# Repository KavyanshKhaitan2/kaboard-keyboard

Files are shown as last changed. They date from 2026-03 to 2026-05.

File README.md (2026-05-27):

# Kaboard!
[[ Showcase video ]](https://youtu.be/ID2R_xTHKyI)

_Yet another mechanical keyboard_

This is the first full-size keyboard I built!

It is a full-size mechanical keyboard with LEDs under each key. The firmware is very customisable, you can customise everything using usevia.app.

## Contents
Quickly jump to different sections of this README.
1. [Why?](#why)
1. [Fallout Zine Page](#zine)
1. [PCB](#pcb)
2. [Schematics](#schematics)
3. [Case](#case)
4. [BOM](#bom)
5. [How do I build it?](#how-do-i-build-it)
## Why?
I wanted to learn how to build a keyboard, so this is how I decided to do that!

## Zine
Kaboard! Zine (1)

## PCB


[ [View in KiCanvas](https://kicanvas.org/?repo=https://github.com/KavyanshKhaitan2/kaboard-keyboard/tree/main/pcb) ]

## Schematics



## Case
[ [View in Onshape](https://cad.onshape.com/documents/8ed13534193dd50e2cf177a7/w/262d5483b57866700addb319/e/d3e08e0b5eff8c35a30b137c) ] 
### Top
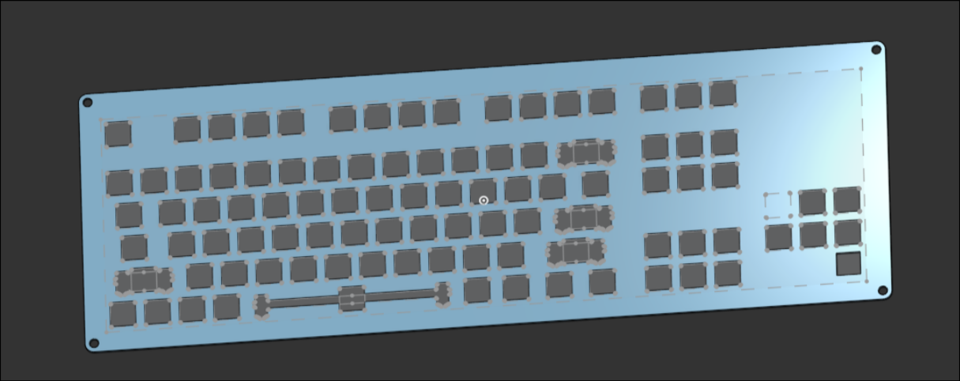
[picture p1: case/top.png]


[ [Download STEP file](https://github.com/KavyanshKhaitan2/kaboard-keyboard/raw/refs/heads/main/case/bottom.step) ]
### Bottom
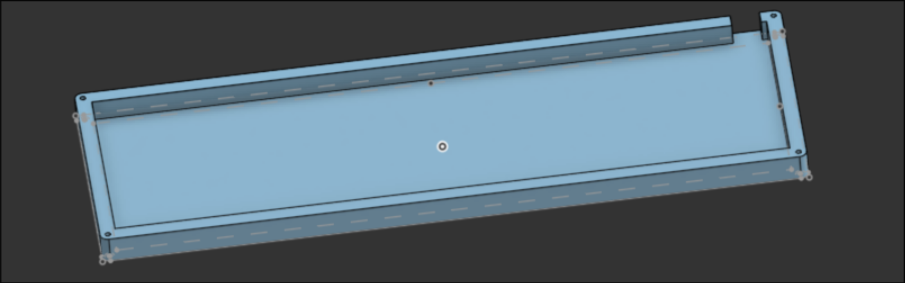
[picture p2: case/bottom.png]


[ [Download STEP file](https://github.com/KavyanshKhaitan2/kaboard-keyboard/raw/refs/heads/main/case/top.step) ]

## BOM
| Item | Qty | Link | Price | Running total |
|---|-----|---|---|---:|
| Keycaps | 1 set |  [StacksKB](https://stackskb.com/store/veekos-gradient-keycaps-cherry-profile-135-keys/) | Rs. 1300 (~ $15) | Rs. 1300 ($15) |
| Switches | 100pc | [CosmicByte](https://www.thecosmicbyte.com/product/gateron-mechanical-switches-compatible-with-cosmic-byte-hot-swappable-keyboards-qty-1pc/) | Rs. 2000 (~ $25) | Rs. 3300 ($40) |
| Resettable Fuse | 1 | [LCSC](https://www.lcsc.com/product-detail/C2153776.html) | $2 (~ Rs. 200) | Rs. 3500 ($42) |
| Raspberry Pi Pico | 1 | [Robu](https://robu.in/product/raspberry-pi-pico/) | Rs. 400 (~ $5) | Rs. 3900 ($47) |
| 1k resistor | 2 | [LCSC](https://www.lcsc.com/product-detail/C119870.html) | $0.60 (~ Rs. 60) | Rs. 3960 ($47.6) |
| 1N4148 diodes | 96 | [LCSC](https://www.lcsc.com/product-detail/C84410.html) | $1.6 (~ Rs. 160) | Rs. 4120 ($49.2) |
| EC11 rotary encoder | 1 | - | 0 | Rs. 4120 ($49.2) |
| SK6812MINI-E | 120 | [LCSC](https://www.lcsc.com/product-detail/C5149201.html?s_z=n_SK6812MINI-E) | $9 (~ Rs. 900) | Rs. 5020 ($58.2) |
| PCB | 1 | AIVON | $25.3 (~Rs. 2300) | Rs. 7320 ($83.5) |
| Keycap Stabilizers | 8 | [StacksKB](https://stackskb.com/store/genuine-cherry-mx-plate-mount-stabilizers-2u/) | Rs. 400 (~$4) | Rs. 7720 ($87.5) |
| Spacebar Stabilizer Wire | 1 | Self fulfilled | Rs. 0 | Rs. 7720 ($87.5) |
| Shipping (Guesstimate) | - | - | $25 (~Rs. 2500) | Rs. 10220 ($112.5) |

## How do I build it?
1. Obtain all of the BoM.
2. Print the 3d case
3. Start soldering the SK6812MINI-Es
4. Solder all the diodes
5. Solder the pi pico from the back
6. Solder the rotary encoder
7. Add the stabilizers to the top part of the case
8. Get the top part of the case and place it over the pcb
9. Get all the switches and place it through the case
10. Solder all the switches that you just placed
11. Plug it in to your computer in BOOTSEL mode
12. Upload the .uf2 firmware file over to the drive that just got mounted
13. Voilla! You are now done!

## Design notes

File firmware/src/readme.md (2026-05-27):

# kaboard

kaboard

*A short description of the keyboard/project*

* Keyboard Maintainer: [Kavyansh Khaitan](https://github.com/KavyanshKhaitan2)
* Hardware Supported: *The PCBs, controllers supported*
* Hardware Availability: *Links to where you can find this hardware*

Make example for this keyboard (after setting up your build environment):

    make kaboard:default

Flashing example for this keyboard:

    make kaboard:default:flash

See the [build environment setup](https://docs.qmk.fm/#/getting_started_build_tools) and the [make instructions](https://docs.qmk.fm/#/getting_started_make_guide) for more information. Brand new to QMK? Start with our [Complete Newbs Guide](https://docs.qmk.fm/#/newbs).

## Bootloader

Enter the bootloader in 3 ways:

* **Bootmagic reset**: Hold down the key at (0,0) in the matrix (usually the top left key or Escape) and plug in the keyboard
* **Physical reset button**: Briefly press the button on the back of the PCB - some may have pads you must short instead
* **Keycode in layout**: Press the key mapped to `QK_BOOT` if it is available

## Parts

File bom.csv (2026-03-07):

Item | Qty | Link | Price | Running total
Keycaps | 1 set | https://stackskb.com/store/veekos-gradient-keycaps-cherry-profile-135-keys/ | Rs. 1300 (~ $15) | Rs. 1300 ($15)
Switches | 100pc | https://www.thecosmicbyte.com/product/gateron-mechanical-switches-compatible-with-cosmic-byte-hot-swappable-keyboards-qty-1pc/ | Rs. 2000 (~ $25) | Rs. 3300 ($40)
Resettable Fuse | 1 | https://www.lcsc.com/product-detail/C2153776.html | $2 (~ Rs. 200) | Rs. 3500 ($42)
Raspberry Pi Pico | 1 | https://robu.in/product/raspberry-pi-pico/ | Rs. 400 (~ $5) | Rs. 3900 ($47)
1k resistor | 2 | https://www.lcsc.com/product-detail/C119870.html | $0.60 (~ Rs. 60) | Rs. 3960 ($47.6)
1N4148 diodes | 96 | https://www.lcsc.com/product-detail/C84410.html | $1.6 (~ Rs. 160) | Rs. 4120 ($49.2)
EC11 rotary encoder | 1 | - | 0 | Rs. 4120 ($49.2)
SK6812MINI-E | 120 | https://www.lcsc.com/product-detail/C5149201.html?s_z=n_SK6812MINI-E | $9 (~ Rs. 900) | Rs. 5020 ($58.2)
PCB | 1 | JLCPCB | $25.3 (~Rs. 2300) | Rs. 7320 ($83.5)
Keycap Stabilizers | 8 | https://stackskb.com/store/genuine-cherry-mx-plate-mount-stabilizers-2u/ | Rs. 400 (~$4) | Rs. 7720 ($87.5)
Keycap Stabilizers | 1 set | https://www.amazon.in/Merishopp-Stabilizers-Precision-Mechanical-Networking/dp/B0FF4F3RZY | Rs. 870 (~$8) | Rs. 8590 ($95.5)
Shipping (Guesstimate) | - | - | $25 (~Rs. 2500) | Rs. 11090 ($120.5)

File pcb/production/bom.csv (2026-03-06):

Designator | Footprint | Quantity | Value | LCSC Part #
A1 | RaspberryPi_Pico_Common_THT | 1 | RaspberryPi_Pico
D1, D10, D11, D12, D13, D14, D15, D16, D17, D18, D19, D192, D2, D20, D21, D22, D23, D24, D25, D26, D27, D28, D29, D3, D30, D32, D33, D34, D35, D36, D37, D38, D39, D4, D40, D41, D42, D43, D44, D45, D46, D47, D48, D49, D5, D50, D51, D52, D53, D54, D55, D56, D57, D58, D59, D6, D60, D61, D62, D63, D64, D65, D66, D67, D68, D69, D7, D70, D71, D72, D73, D74, D75, D76, D77, D78, D79, D8, D80, D81, D82, D83, D84, D85, D86, D87, D88, D89, D9, D90, D91, D92, D93, D94, D95, D96 | D_DO-41_SOD81_P7.62mm_Horizontal | 96 | D
F1 | Fuse_Littelfuse_372_D8.50mm | 1 | 1.6A
LED1, LED10, LED100, LED101, LED102, LED11, LED12, LED13, LED14, LED15, LED16, LED17, LED18, LED19, LED2, LED20, LED201, LED21, LED22, LED23, LED24, LED25, LED26, LED27, LED28, LED29, LED3, LED30, LED31, LED32, LED33, LED34, LED35, LED36, LED37, LED38, LED39, LED4, LED40, LED41, LED42, LED43, LED44, LED45, LED46, LED47, LED48, LED49, LED5, LED50, LED51, LED52, LED53, LED54, LED55, LED56, LED57, LED58, LED59, LED6, LED60, LED61, LED62, LED63, LED64, LED65, LED66, LED67, LED68, LED69, LED7, LED70, LED71, LED72, LED73, LED74, LED75, LED76, LED77, LED78, LED79, LED8, LED80, LED81, LED82, LED83, LED84, LED85, LED86, LED87, LED88, LED89, LED9, LED90, LED91, LED92, LED93, LED94, LED95, LED96, LED97, LED98, LED99 | MX_SK6812MINI-E_REV | 103 | SK6812MINI-E
MX1, MX10, MX11, MX12, MX13, MX14, MX15, MX16, MX17, MX18, MX19, MX2, MX20, MX21, MX22, MX23, MX24, MX25, MX26, MX27, MX28, MX29, MX3, MX30, MX32, MX33, MX34, MX35, MX36, MX37, MX38, MX39, MX4, MX40, MX41, MX42, MX43, MX44, MX45, MX46, MX47, MX48, MX49, MX5, MX50, MX51, MX52, MX53, MX54, MX55, MX56, MX57, MX58, MX59, MX6, MX60, MX61, MX62, MX63, MX64, MX65, MX66, MX67, MX68, MX69, MX7, MX70, MX71, MX72, MX73, MX74, MX75, MX76, MX77, MX78, MX79, MX8, MX80, MX81, MX82, MX83, MX84, MX85, MX86, MX87, MX88, MX89, MX9, MX90, MX91, MX92, MX93, MX94, MX95, MX96 | SW_Cherry_MX_1.00u_PCB_withSwitch | 95 | MX_SW_HS
R1, R2 | R_Axial_DIN0204_L3.6mm_D1.6mm_P5.08mm_Horizontal | 2 | 1K
SW1 | RotaryEncoder_Alps_EC11E-Switch_Vertical_H20mm | 1 | RotaryEncoder_Switch

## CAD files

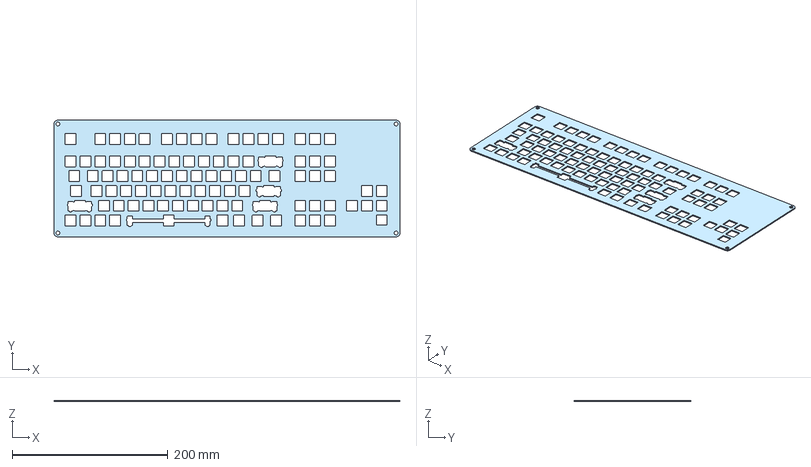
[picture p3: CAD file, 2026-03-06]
case/top.step
444.8 x 150.1 x 1.50 mm

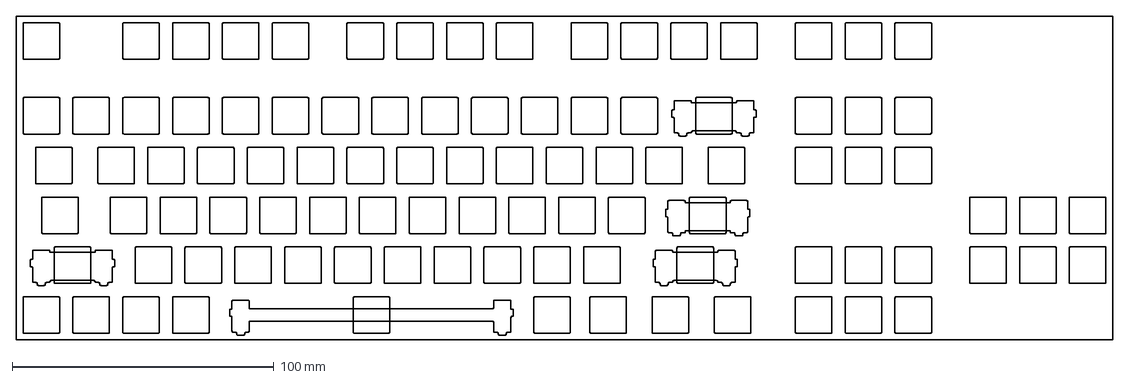
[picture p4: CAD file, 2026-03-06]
plate-2026-03-01T12_22_32.903Z.dxf
419.1 x 123.8 mm

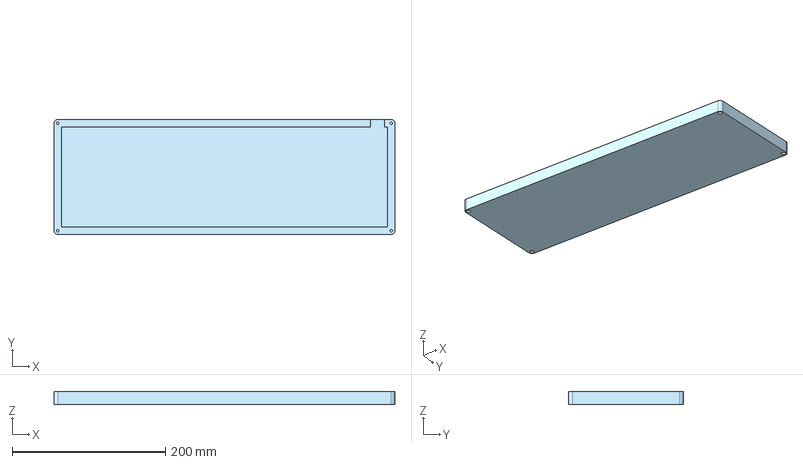
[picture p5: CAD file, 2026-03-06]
case/bottom.step
444.8 x 150.1 x 17.1 mm

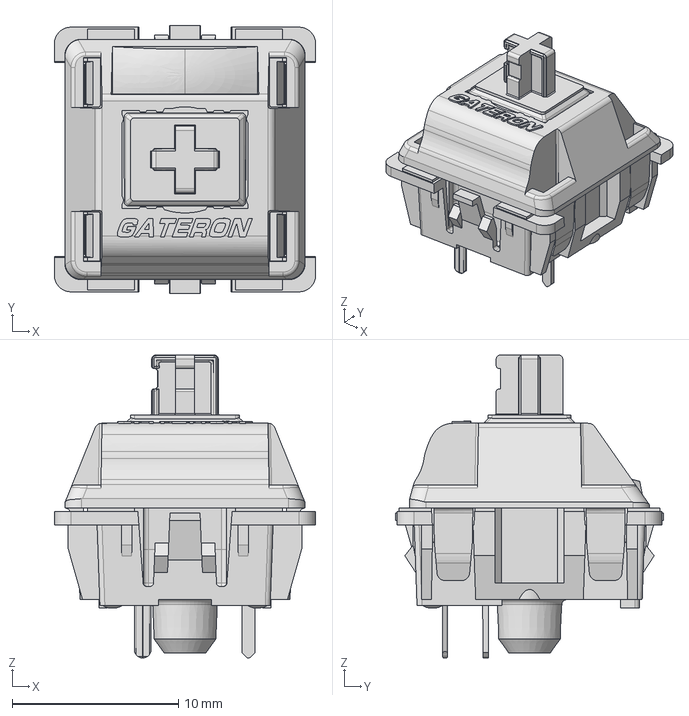
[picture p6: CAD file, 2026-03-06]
G PRO 3.0 Switch KS-9E10B055NN-Y51.stp
15.7 x 16.1 x 18.2 mm

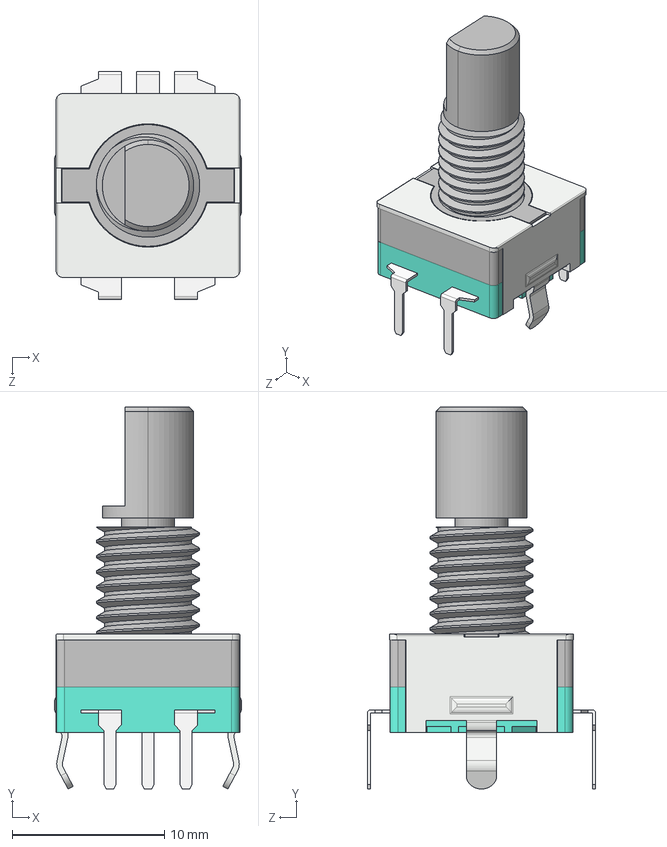
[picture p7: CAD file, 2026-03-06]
EC11 3d model.step
12.3 x 25.1 x 15.0 mm

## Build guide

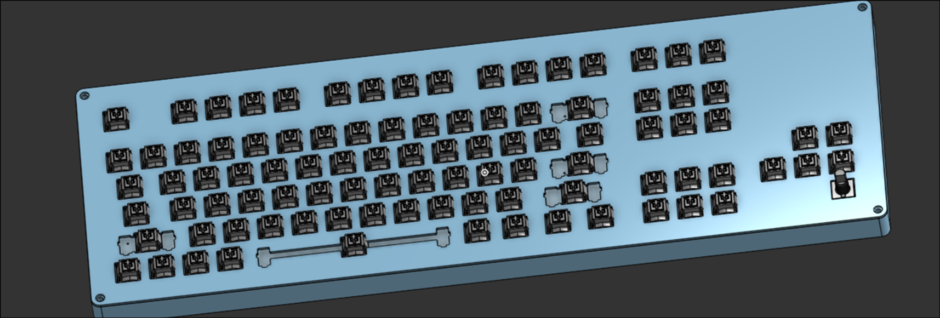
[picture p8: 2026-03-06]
case/assembled.png

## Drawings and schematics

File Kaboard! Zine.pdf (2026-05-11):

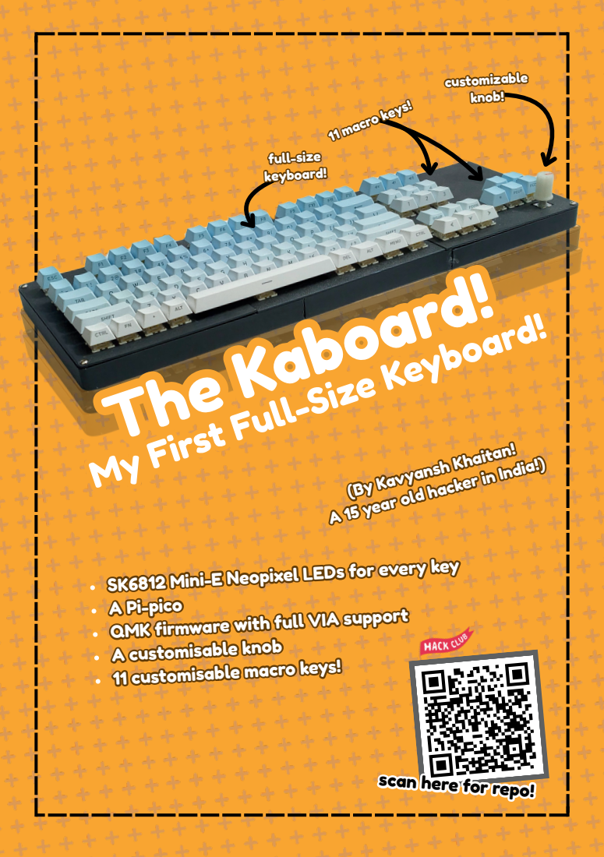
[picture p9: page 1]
The Kaboard!; A Pi-pico; A customisable knob; customizable knob!; full-size keyboard!; 11 macro keys!

My First Full-Size Keyboard!

(By Kavyansh Khaitan!

A 15 year old hacker in India!)

SK6812 Mini-E Neopixel LEDs for every key

QMK firmware with full VIA support

11 customisable macro keys!

scan here for repo!

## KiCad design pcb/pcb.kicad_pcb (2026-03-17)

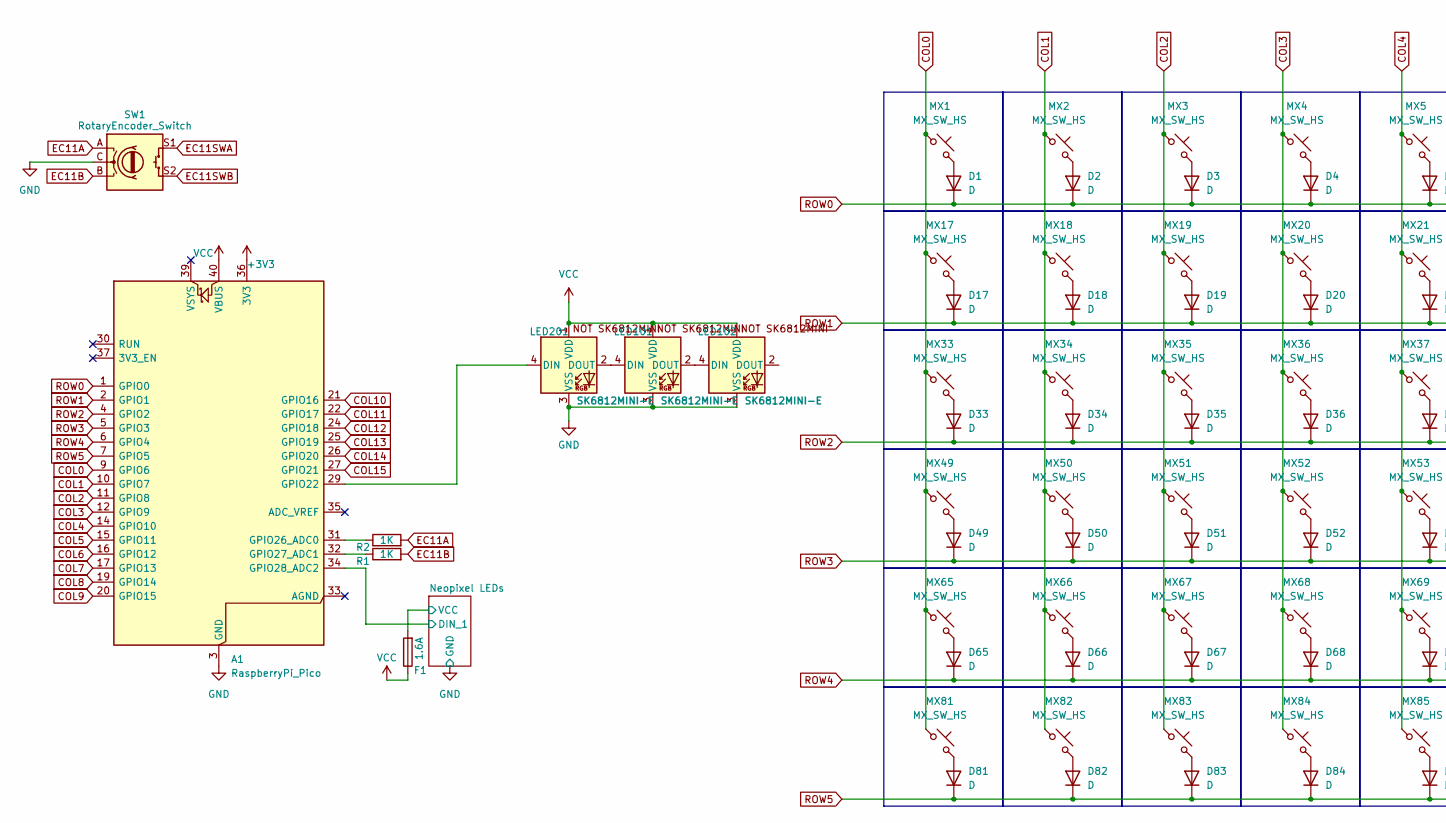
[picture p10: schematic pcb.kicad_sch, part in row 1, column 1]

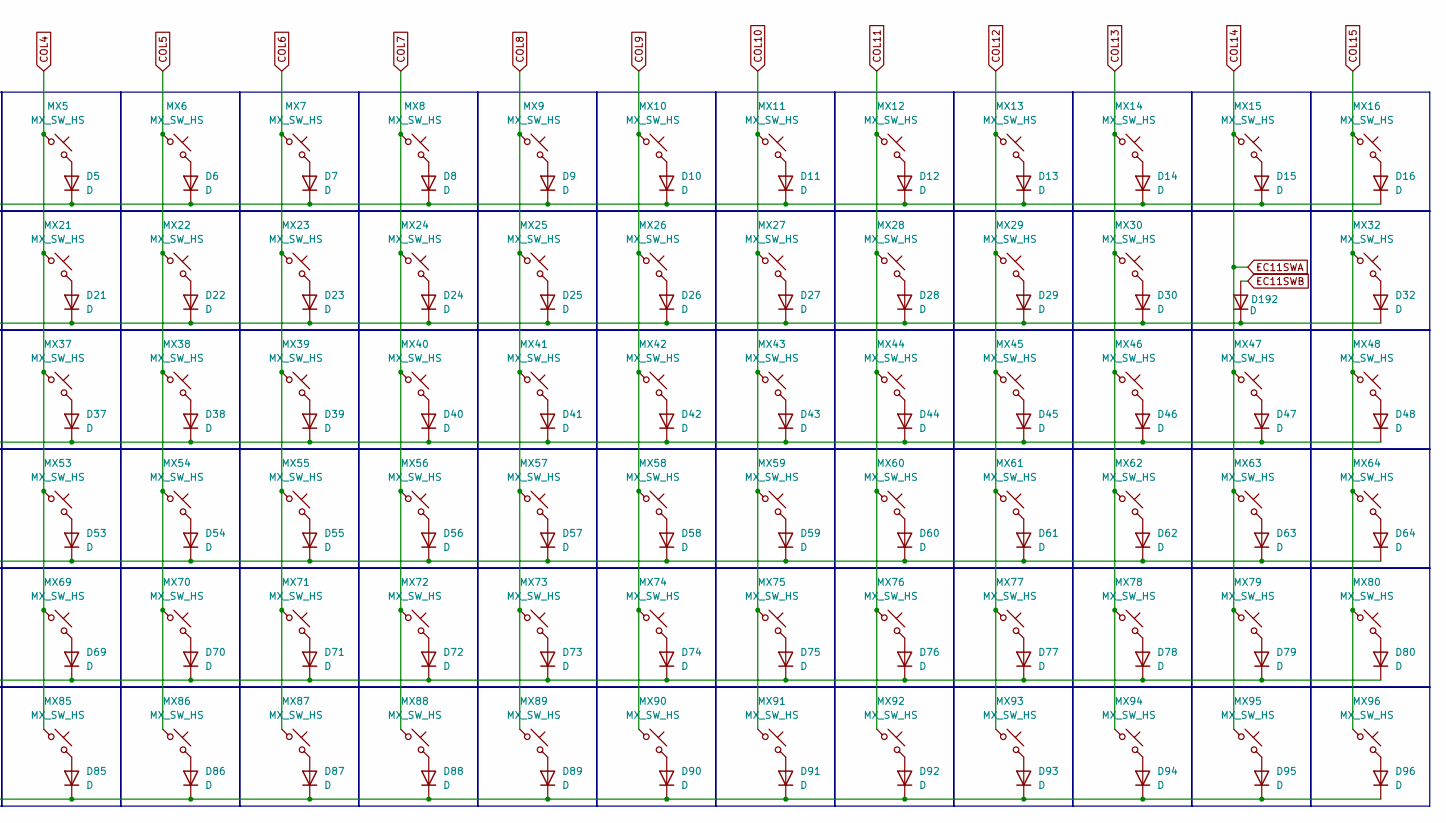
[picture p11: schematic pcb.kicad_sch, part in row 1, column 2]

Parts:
A1: RaspberryPi_Pico; RaspberryPi_Pico_Common_THT
D1, D2, D3, D4, D5, D6, D7, D8, D9, D10, D11, D12, D13, D14, D15, D16, D17, D18, D19, D20, D21, D22, D23, D24, D25, D26, D27, D28, D29, D30, D32, D33, D34, D35, D36, D37, D38, D39, D40, D41, D42, D43, D44, D45, D46, D47, D48, D49, D50, D51, D52, D53, D54, D55, D56, D57, D58, D59, D60, D61, D62, D63, D64, D65, D66, D67, D68, D69, D70, D71, D72, D73, D74, D75, D76, D77, D78, D79, D80, D81, D82, D83, D84, D85, D86, D87, D88, D89, D90, D91, D92, D93, D94, D95, D96, D192: D; D_DO-41_SOD81_P7.62mm_Horizontal
F1: 1.6A; Fuse_Littelfuse_372_D8.50mm
LED101, LED102, LED201: SK6812MINI-E; MX_SK6812MINI-E_REV
MX1, MX2, MX3, MX4, MX5, MX6, MX7, MX8, MX9, MX10, MX11, MX12, MX13, MX14, MX15, MX16, MX17, MX18, MX19, MX20, MX21, MX22, MX23, MX24, MX25, MX26, MX27, MX28, MX29, MX30, MX32, MX33, MX34, MX35, MX36, MX37, MX38, MX39, MX40, MX41, MX42, MX43, MX44, MX45, MX46, MX47, MX48, MX49, MX50, MX51, MX52, MX53, MX54, MX55, MX56, MX57, MX58, MX59, MX60, MX61, MX62, MX63, MX64, MX65, MX66, MX67, MX68, MX69, MX70, MX71, MX72, MX73, MX74, MX75, MX76, MX77, MX78, MX79, MX80, MX81, MX82, MX83, MX84, MX85, MX86, MX87, MX88, MX89, MX90, MX91, MX92, MX93, MX94, MX95, MX96: MX_SW_HS; SW_Cherry_MX_1.00u_PCB_withSwitch
R1, R2: 1K; R_Axial_DIN0204_L3.6mm_D1.6mm_P5.08mm_Horizontal
SW1: RotaryEncoder_Switch; RotaryEncoder_Alps_EC11E-Switch_Vertical_H20mm

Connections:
+3V3: A1.36 (3V3)
/Neopixel LEDs/DIN_1: A1.34 (GPIO28_ADC2); also elsewhere on the board
COL0: A1.9 (GPIO6), MX1.1, MX17.1, MX33.1, MX49.1, MX65.1, MX81.1
COL1: A1.10 (GPIO7), MX2.1, MX18.1, MX34.1, MX50.1, MX66.1, MX82.1
COL2: A1.11 (GPIO8), MX3.1, MX19.1, MX35.1, MX51.1, MX67.1, MX83.1
COL3: A1.12 (GPIO9), MX4.1, MX20.1, MX36.1, MX52.1, MX68.1, MX84.1
COL4: A1.14 (GPIO10), MX5.1, MX21.1, MX37.1, MX53.1, MX69.1, MX85.1
COL5: A1.15 (GPIO11), MX6.1, MX22.1, MX38.1, MX54.1, MX70.1, MX86.1
COL6: A1.16 (GPIO12), MX7.1, MX23.1, MX39.1, MX55.1, MX71.1, MX87.1
COL7: A1.17 (GPIO13), MX8.1, MX24.1, MX40.1, MX56.1, MX72.1, MX88.1
COL8: A1.19 (GPIO14), MX9.1, MX25.1, MX41.1, MX57.1, MX73.1, MX89.1
COL9: A1.20 (GPIO15), MX10.1, MX26.1, MX42.1, MX58.1, MX74.1, MX90.1
COL10: A1.21 (GPIO16), MX11.1, MX27.1, MX43.1, MX59.1, MX75.1, MX91.1
COL11: A1.22 (GPIO17), MX12.1, MX28.1, MX44.1, MX60.1, MX76.1, MX92.1
COL12: A1.24 (GPIO18), MX13.1, MX29.1, MX45.1, MX61.1, MX77.1, MX93.1
COL13: A1.25 (GPIO19), MX14.1, MX30.1, MX46.1, MX62.1, MX78.1, MX94.1
COL14: A1.26 (GPIO20), MX15.1, MX47.1, MX63.1, MX79.1, MX95.1, SW1.S1
COL15: A1.27 (GPIO21), MX16.1, MX32.1, MX48.1, MX64.1, MX80.1, MX96.1
EC11A: R2.2, SW1.A
EC11B: R1.2, SW1.B
EC11SWB: D192.2 (A), SW1.S2
GND: A1.3 (GND), A1.8 (GND), A1.13 (GND), A1.18 (GND), A1.23 (GND), A1.28 (GND), A1.38 (GND), LED101.3 (VSS), LED102.3 (VSS), LED201.3 (VSS), SW1.C; also elsewhere on the board
unnamed: A1.29 (GPIO22), LED201.4 (DIN)
unnamed: A1.31 (GPIO26_ADC0), R2.1
unnamed: A1.32 (GPIO27_ADC1), R1.1
unnamed: D1.2 (A), MX1.2
unnamed: D2.2 (A), MX2.2
unnamed: D3.2 (A), MX3.2
unnamed: D4.2 (A), MX4.2
unnamed: D5.2 (A), MX5.2
unnamed: D6.2 (A), MX6.2
unnamed: D7.2 (A), MX7.2
unnamed: D8.2 (A), MX8.2
unnamed: D9.2 (A), MX9.2
unnamed: D10.2 (A), MX10.2
unnamed: D11.2 (A), MX11.2
unnamed: D12.2 (A), MX12.2
unnamed: D13.2 (A), MX13.2
unnamed: D14.2 (A), MX14.2
unnamed: D15.2 (A), MX15.2
unnamed: D16.2 (A), MX16.2
unnamed: D17.2 (A), MX17.2
unnamed: D18.2 (A), MX18.2
unnamed: D19.2 (A), MX19.2
unnamed: D20.2 (A), MX20.2
unnamed: D21.2 (A), MX21.2
unnamed: D22.2 (A), MX22.2
unnamed: D23.2 (A), MX23.2
unnamed: D24.2 (A), MX24.2
unnamed: D25.2 (A), MX25.2
unnamed: D26.2 (A), MX26.2
unnamed: D27.2 (A), MX27.2
unnamed: D28.2 (A), MX28.2
unnamed: D29.2 (A), MX29.2
unnamed: D30.2 (A), MX30.2
unnamed: D32.2 (A), MX32.2
unnamed: D33.2 (A), MX33.2
unnamed: D34.2 (A), MX34.2
unnamed: D35.2 (A), MX35.2
unnamed: D36.2 (A), MX36.2
unnamed: D37.2 (A), MX37.2
unnamed: D38.2 (A), MX38.2
unnamed: D39.2 (A), MX39.2
unnamed: D40.2 (A), MX40.2
unnamed: D41.2 (A), MX41.2
unnamed: D42.2 (A), MX42.2
unnamed: D43.2 (A), MX43.2
unnamed: D44.2 (A), MX44.2
unnamed: D45.2 (A), MX45.2
unnamed: D46.2 (A), MX46.2
unnamed: D47.2 (A), MX47.2
unnamed: D48.2 (A), MX48.2
unnamed: D49.2 (A), MX49.2
unnamed: D50.2 (A), MX50.2
unnamed: D51.2 (A), MX51.2
unnamed: D52.2 (A), MX52.2
unnamed: D53.2 (A), MX53.2
unnamed: D54.2 (A), MX54.2
unnamed: D55.2 (A), MX55.2
unnamed: D56.2 (A), MX56.2
unnamed: D57.2 (A), MX57.2
unnamed: D58.2 (A), MX58.2
unnamed: D59.2 (A), MX59.2
unnamed: D60.2 (A), MX60.2
unnamed: D61.2 (A), MX61.2
unnamed: D62.2 (A), MX62.2
unnamed: D63.2 (A), MX63.2
unnamed: D64.2 (A), MX64.2
unnamed: D65.2 (A), MX65.2
unnamed: D66.2 (A), MX66.2
unnamed: D67.2 (A), MX67.2
unnamed: D68.2 (A), MX68.2
unnamed: D69.2 (A), MX69.2
unnamed: D70.2 (A), MX70.2
unnamed: D71.2 (A), MX71.2
unnamed: D72.2 (A), MX72.2
unnamed: D73.2 (A), MX73.2
unnamed: D74.2 (A), MX74.2
unnamed: D75.2 (A), MX75.2
unnamed: D76.2 (A), MX76.2
unnamed: D77.2 (A), MX77.2
unnamed: D78.2 (A), MX78.2
unnamed: D79.2 (A), MX79.2
unnamed: D80.2 (A), MX80.2
unnamed: D81.2 (A), MX81.2
unnamed: D82.2 (A), MX82.2
unnamed: D83.2 (A), MX83.2
unnamed: D84.2 (A), MX84.2
unnamed: D85.2 (A), MX85.2
unnamed: D86.2 (A), MX86.2
unnamed: D87.2 (A), MX87.2
unnamed: D88.2 (A), MX88.2
unnamed: D89.2 (A), MX89.2
unnamed: D90.2 (A), MX90.2
unnamed: D91.2 (A), MX91.2
unnamed: D92.2 (A), MX92.2
unnamed: D93.2 (A), MX93.2
unnamed: D94.2 (A), MX94.2
unnamed: D95.2 (A), MX95.2
unnamed: D96.2 (A), MX96.2
unnamed: LED101.4 (DIN), LED201.2 (DOUT)
unnamed: LED101.2 (DOUT), LED102.4 (DIN)
ROW0: A1.1 (GPIO0), D1.1 (K), D2.1 (K), D3.1 (K), D4.1 (K), D5.1 (K), D6.1 (K), D7.1 (K), D8.1 (K), D9.1 (K), D10.1 (K), D11.1 (K), D12.1 (K), D13.1 (K), D14.1 (K), D15.1 (K), D16.1 (K)
ROW1: A1.2 (GPIO1), D17.1 (K), D18.1 (K), D19.1 (K), D20.1 (K), D21.1 (K), D22.1 (K), D23.1 (K), D24.1 (K), D25.1 (K), D26.1 (K), D27.1 (K), D28.1 (K), D29.1 (K), D30.1 (K), D32.1 (K), D192.1 (K)
ROW2: A1.4 (GPIO2), D33.1 (K), D34.1 (K), D35.1 (K), D36.1 (K), D37.1 (K), D38.1 (K), D39.1 (K), D40.1 (K), D41.1 (K), D42.1 (K), D43.1 (K), D44.1 (K), D45.1 (K), D46.1 (K), D47.1 (K), D48.1 (K)
ROW3: A1.5 (GPIO3), D49.1 (K), D50.1 (K), D51.1 (K), D52.1 (K), D53.1 (K), D54.1 (K), D55.1 (K), D56.1 (K), D57.1 (K), D58.1 (K), D59.1 (K), D60.1 (K), D61.1 (K), D62.1 (K), D63.1 (K), D64.1 (K)
ROW4: A1.6 (GPIO4), D65.1 (K), D66.1 (K), D67.1 (K), D68.1 (K), D69.1 (K), D70.1 (K), D71.1 (K), D72.1 (K), D73.1 (K), D74.1 (K), D75.1 (K), D76.1 (K), D77.1 (K), D78.1 (K), D79.1 (K), D80.1 (K)
ROW5: A1.7 (GPIO5), D81.1 (K), D82.1 (K), D83.1 (K), D84.1 (K), D85.1 (K), D86.1 (K), D87.1 (K), D88.1 (K), D89.1 (K), D90.1 (K), D91.1 (K), D92.1 (K), D93.1 (K), D94.1 (K), D95.1 (K), D96.1 (K)
VCC: A1.40 (VBUS), F1.1, F1.2, LED101.1 (VDD), LED102.1 (VDD), LED201.1 (VDD); also elsewhere on the board

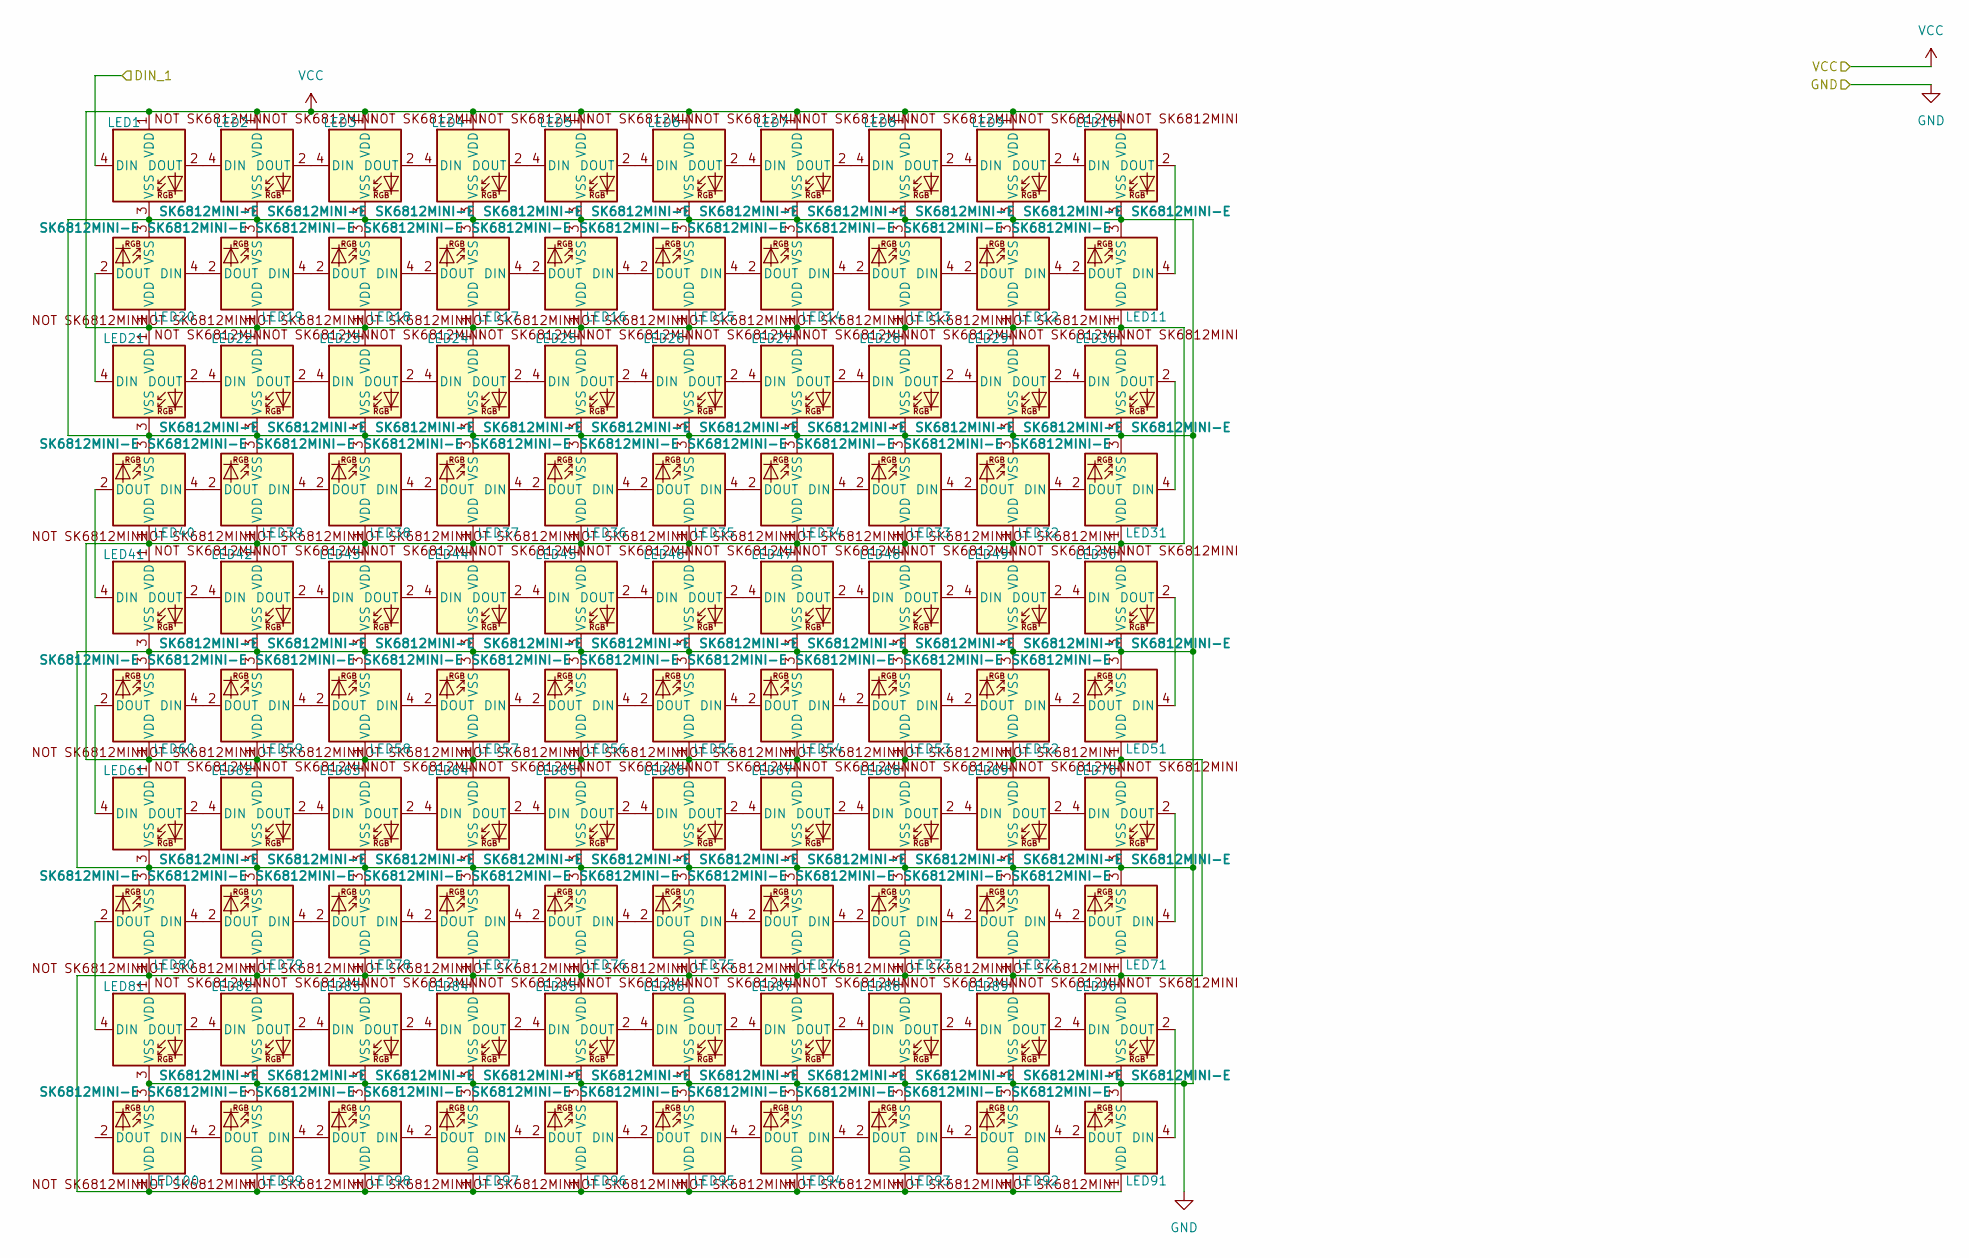
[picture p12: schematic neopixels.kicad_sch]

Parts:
LED1, LED2, LED3, LED4, LED5, LED6, LED7, LED8, LED9, LED10, LED11, LED12, LED13, LED14, LED15, LED16, LED17, LED18, LED19, LED20, LED21, LED22, LED23, LED24, LED25, LED26, LED27, LED28, LED29, LED30, LED31, LED32, LED33, LED34, LED35, LED36, LED37, LED38, LED39, LED40, LED41, LED42, LED43, LED44, LED45, LED46, LED47, LED48, LED49, LED50, LED51, LED52, LED53, LED54, LED55, LED56, LED57, LED58, LED59, LED60, LED61, LED62, LED63, LED64, LED65, LED66, LED67, LED68, LED69, LED70, LED71, LED72, LED73, LED74, LED75, LED76, LED77, LED78, LED79, LED80, LED81, LED82, LED83, LED84, LED85, LED86, LED87, LED88, LED89, LED90, LED91, LED92, LED93, LED94, LED95, LED96, LED97, LED98, LED99, LED100: SK6812MINI-E; MX_SK6812MINI-E_REV

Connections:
/Neopixel LEDs/DIN_1: LED1.4 (DIN); also elsewhere on the board
GND: LED1.3 (VSS), LED2.3 (VSS), LED3.3 (VSS), LED4.3 (VSS), LED5.3 (VSS), LED6.3 (VSS), LED7.3 (VSS), LED8.3 (VSS), LED9.3 (VSS), LED10.3 (VSS), LED11.3 (VSS), LED12.3 (VSS), LED13.3 (VSS), LED14.3 (VSS), LED15.3 (VSS), LED16.3 (VSS), LED17.3 (VSS), LED18.3 (VSS), LED19.3 (VSS), LED20.3 (VSS), LED21.3 (VSS), LED22.3 (VSS), LED23.3 (VSS), LED24.3 (VSS), LED25.3 (VSS), LED26.3 (VSS), LED27.3 (VSS), LED28.3 (VSS), LED29.3 (VSS), LED30.3 (VSS), LED31.3 (VSS), LED32.3 (VSS), LED33.3 (VSS), LED34.3 (VSS), LED35.3 (VSS), LED36.3 (VSS), LED37.3 (VSS), LED38.3 (VSS), LED39.3 (VSS), LED40.3 (VSS), LED41.3 (VSS), LED42.3 (VSS), LED43.3 (VSS), LED44.3 (VSS), LED45.3 (VSS), LED46.3 (VSS), LED47.3 (VSS), LED48.3 (VSS), LED49.3 (VSS), LED50.3 (VSS), LED51.3 (VSS), LED52.3 (VSS), LED53.3 (VSS), LED54.3 (VSS), LED55.3 (VSS), LED56.3 (VSS), LED57.3 (VSS), LED58.3 (VSS), LED59.3 (VSS), LED60.3 (VSS), LED61.3 (VSS), LED62.3 (VSS), LED63.3 (VSS), LED64.3 (VSS), LED65.3 (VSS), LED66.3 (VSS), LED67.3 (VSS), LED68.3 (VSS), LED69.3 (VSS), LED70.3 (VSS), LED71.3 (VSS), LED72.3 (VSS), LED73.3 (VSS), LED74.3 (VSS), LED75.3 (VSS), LED76.3 (VSS), LED77.3 (VSS), LED78.3 (VSS), LED79.3 (VSS), LED80.3 (VSS), LED81.3 (VSS), LED82.3 (VSS), LED83.3 (VSS), LED84.3 (VSS), LED85.3 (VSS), LED86.3 (VSS), LED87.3 (VSS), LED88.3 (VSS), LED89.3 (VSS), LED90.3 (VSS), LED91.3 (VSS), LED92.3 (VSS), LED93.3 (VSS), LED94.3 (VSS), LED95.3 (VSS), LED96.3 (VSS), LED97.3 (VSS), LED98.3 (VSS), LED99.3 (VSS), LED100.3 (VSS); also elsewhere on the board
unnamed: LED1.2 (DOUT), LED2.4 (DIN)
unnamed: LED2.2 (DOUT), LED3.4 (DIN)
unnamed: LED3.2 (DOUT), LED4.4 (DIN)
unnamed: LED4.2 (DOUT), LED5.4 (DIN)
unnamed: LED5.2 (DOUT), LED6.4 (DIN)
unnamed: LED6.2 (DOUT), LED7.4 (DIN)
unnamed: LED7.2 (DOUT), LED8.4 (DIN)
unnamed: LED8.2 (DOUT), LED9.4 (DIN)
unnamed: LED9.2 (DOUT), LED10.4 (DIN)
unnamed: LED10.2 (DOUT), LED11.4 (DIN)
unnamed: LED11.2 (DOUT), LED12.4 (DIN)
unnamed: LED12.2 (DOUT), LED13.4 (DIN)
unnamed: LED13.2 (DOUT), LED14.4 (DIN)
unnamed: LED14.2 (DOUT), LED15.4 (DIN)
unnamed: LED15.2 (DOUT), LED16.4 (DIN)
unnamed: LED16.2 (DOUT), LED17.4 (DIN)
unnamed: LED17.2 (DOUT), LED18.4 (DIN)
unnamed: LED18.2 (DOUT), LED19.4 (DIN)
unnamed: LED19.2 (DOUT), LED20.4 (DIN)
unnamed: LED20.2 (DOUT), LED21.4 (DIN)
unnamed: LED21.2 (DOUT), LED22.4 (DIN)
unnamed: LED22.2 (DOUT), LED23.4 (DIN)
unnamed: LED23.2 (DOUT), LED24.4 (DIN)
unnamed: LED24.2 (DOUT), LED25.4 (DIN)
unnamed: LED25.2 (DOUT), LED26.4 (DIN)
unnamed: LED26.2 (DOUT), LED27.4 (DIN)
unnamed: LED27.2 (DOUT), LED28.4 (DIN)
unnamed: LED28.2 (DOUT), LED29.4 (DIN)
unnamed: LED29.2 (DOUT), LED30.4 (DIN)
unnamed: LED30.2 (DOUT), LED31.4 (DIN)
unnamed: LED31.2 (DOUT), LED32.4 (DIN)
unnamed: LED32.2 (DOUT), LED33.4 (DIN)
unnamed: LED33.2 (DOUT), LED34.4 (DIN)
unnamed: LED34.2 (DOUT), LED35.4 (DIN)
unnamed: LED35.2 (DOUT), LED36.4 (DIN)
unnamed: LED36.2 (DOUT), LED37.4 (DIN)
unnamed: LED37.2 (DOUT), LED38.4 (DIN)
unnamed: LED38.2 (DOUT), LED39.4 (DIN)
unnamed: LED39.2 (DOUT), LED40.4 (DIN)
unnamed: LED40.2 (DOUT), LED41.4 (DIN)
unnamed: LED41.2 (DOUT), LED42.4 (DIN)
unnamed: LED42.2 (DOUT), LED43.4 (DIN)
unnamed: LED43.2 (DOUT), LED44.4 (DIN)
unnamed: LED44.2 (DOUT), LED45.4 (DIN)
unnamed: LED45.2 (DOUT), LED46.4 (DIN)
unnamed: LED46.2 (DOUT), LED47.4 (DIN)
unnamed: LED47.2 (DOUT), LED48.4 (DIN)
unnamed: LED48.2 (DOUT), LED49.4 (DIN)
unnamed: LED49.2 (DOUT), LED50.4 (DIN)
unnamed: LED50.2 (DOUT), LED51.4 (DIN)
unnamed: LED51.2 (DOUT), LED52.4 (DIN)
unnamed: LED52.2 (DOUT), LED53.4 (DIN)
unnamed: LED53.2 (DOUT), LED54.4 (DIN)
unnamed: LED54.2 (DOUT), LED55.4 (DIN)
unnamed: LED55.2 (DOUT), LED56.4 (DIN)
unnamed: LED56.2 (DOUT), LED57.4 (DIN)
unnamed: LED57.2 (DOUT), LED58.4 (DIN)
unnamed: LED58.2 (DOUT), LED59.4 (DIN)
unnamed: LED59.2 (DOUT), LED60.4 (DIN)
unnamed: LED60.2 (DOUT), LED61.4 (DIN)
unnamed: LED61.2 (DOUT), LED62.4 (DIN)
unnamed: LED62.2 (DOUT), LED63.4 (DIN)
unnamed: LED63.2 (DOUT), LED64.4 (DIN)
unnamed: LED64.2 (DOUT), LED65.4 (DIN)
unnamed: LED65.2 (DOUT), LED66.4 (DIN)
unnamed: LED66.2 (DOUT), LED67.4 (DIN)
unnamed: LED67.2 (DOUT), LED68.4 (DIN)
unnamed: LED68.2 (DOUT), LED69.4 (DIN)
unnamed: LED69.2 (DOUT), LED70.4 (DIN)
unnamed: LED70.2 (DOUT), LED71.4 (DIN)
unnamed: LED71.2 (DOUT), LED72.4 (DIN)
unnamed: LED72.2 (DOUT), LED73.4 (DIN)
unnamed: LED73.2 (DOUT), LED74.4 (DIN)
unnamed: LED74.2 (DOUT), LED75.4 (DIN)
unnamed: LED75.2 (DOUT), LED76.4 (DIN)
unnamed: LED76.2 (DOUT), LED77.4 (DIN)
unnamed: LED77.2 (DOUT), LED78.4 (DIN)
unnamed: LED78.2 (DOUT), LED79.4 (DIN)
unnamed: LED79.2 (DOUT), LED80.4 (DIN)
unnamed: LED80.2 (DOUT), LED81.4 (DIN)
unnamed: LED81.2 (DOUT), LED82.4 (DIN)
unnamed: LED82.2 (DOUT), LED83.4 (DIN)
unnamed: LED83.2 (DOUT), LED84.4 (DIN)
unnamed: LED84.2 (DOUT), LED85.4 (DIN)
unnamed: LED85.2 (DOUT), LED86.4 (DIN)
unnamed: LED86.2 (DOUT), LED87.4 (DIN)
unnamed: LED87.2 (DOUT), LED88.4 (DIN)
unnamed: LED88.2 (DOUT), LED89.4 (DIN)
unnamed: LED89.2 (DOUT), LED90.4 (DIN)
unnamed: LED90.2 (DOUT), LED91.4 (DIN)
unnamed: LED91.2 (DOUT), LED92.4 (DIN)
unnamed: LED92.2 (DOUT), LED93.4 (DIN)
unnamed: LED93.2 (DOUT), LED94.4 (DIN)
unnamed: LED94.2 (DOUT), LED95.4 (DIN)
unnamed: LED95.2 (DOUT), LED96.4 (DIN)
unnamed: LED96.2 (DOUT), LED97.4 (DIN)
unnamed: LED97.2 (DOUT), LED98.4 (DIN)
unnamed: LED98.2 (DOUT), LED99.4 (DIN)
unnamed: LED99.2 (DOUT), LED100.4 (DIN)
VCC: LED1.1 (VDD), LED2.1 (VDD), LED3.1 (VDD), LED4.1 (VDD), LED5.1 (VDD), LED6.1 (VDD), LED7.1 (VDD), LED8.1 (VDD), LED9.1 (VDD), LED10.1 (VDD), LED11.1 (VDD), LED12.1 (VDD), LED13.1 (VDD), LED14.1 (VDD), LED15.1 (VDD), LED16.1 (VDD), LED17.1 (VDD), LED18.1 (VDD), LED19.1 (VDD), LED20.1 (VDD), LED21.1 (VDD), LED22.1 (VDD), LED23.1 (VDD), LED24.1 (VDD), LED25.1 (VDD), LED26.1 (VDD), LED27.1 (VDD), LED28.1 (VDD), LED29.1 (VDD), LED30.1 (VDD), LED31.1 (VDD), LED32.1 (VDD), LED33.1 (VDD), LED34.1 (VDD), LED35.1 (VDD), LED36.1 (VDD), LED37.1 (VDD), LED38.1 (VDD), LED39.1 (VDD), LED40.1 (VDD), LED41.1 (VDD), LED42.1 (VDD), LED43.1 (VDD), LED44.1 (VDD), LED45.1 (VDD), LED46.1 (VDD), LED47.1 (VDD), LED48.1 (VDD), LED49.1 (VDD), LED50.1 (VDD), LED51.1 (VDD), LED52.1 (VDD), LED53.1 (VDD), LED54.1 (VDD), LED55.1 (VDD), LED56.1 (VDD), LED57.1 (VDD), LED58.1 (VDD), LED59.1 (VDD), LED60.1 (VDD), LED61.1 (VDD), LED62.1 (VDD), LED63.1 (VDD), LED64.1 (VDD), LED65.1 (VDD), LED66.1 (VDD), LED67.1 (VDD), LED68.1 (VDD), LED69.1 (VDD), LED70.1 (VDD), LED71.1 (VDD), LED72.1 (VDD), LED73.1 (VDD), LED74.1 (VDD), LED75.1 (VDD), LED76.1 (VDD), LED77.1 (VDD), LED78.1 (VDD), LED79.1 (VDD), LED80.1 (VDD), LED81.1 (VDD), LED82.1 (VDD), LED83.1 (VDD), LED84.1 (VDD), LED85.1 (VDD), LED86.1 (VDD), LED87.1 (VDD), LED88.1 (VDD), LED89.1 (VDD), LED90.1 (VDD), LED91.1 (VDD), LED92.1 (VDD), LED93.1 (VDD), LED94.1 (VDD), LED95.1 (VDD), LED96.1 (VDD), LED97.1 (VDD), LED98.1 (VDD), LED99.1 (VDD), LED100.1 (VDD); also elsewhere on the board

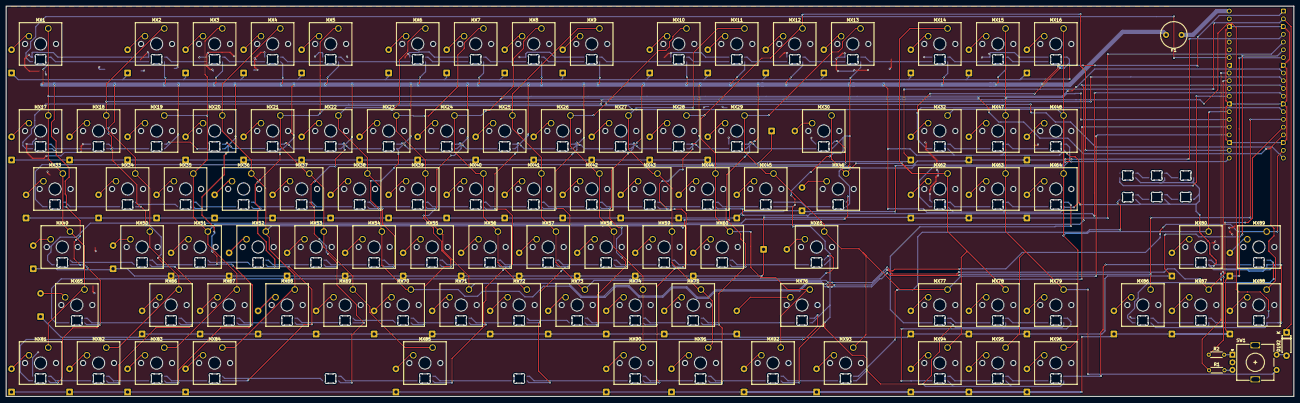
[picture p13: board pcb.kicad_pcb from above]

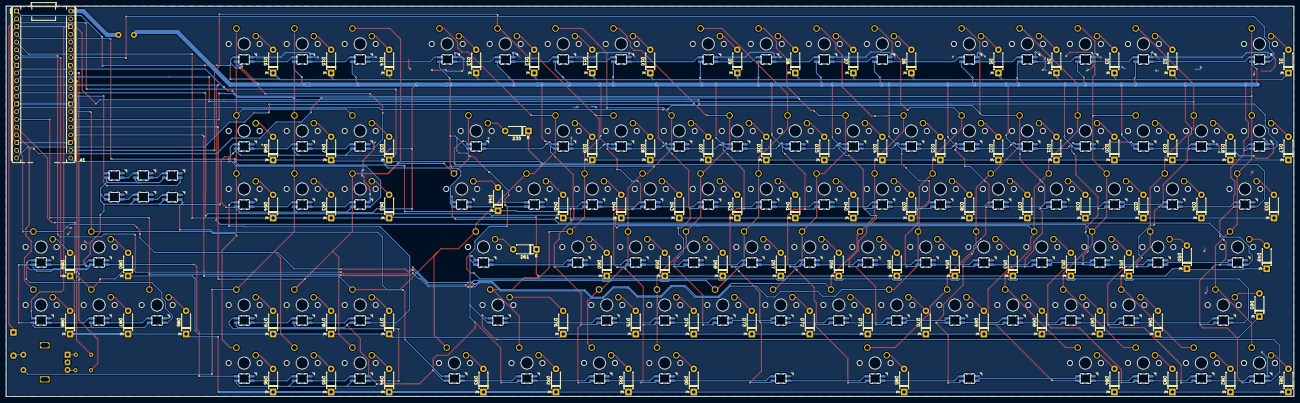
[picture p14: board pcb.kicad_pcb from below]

Board: 2 copper layers, 422.8 x 128.1 mm, 299 parts (96 on the bottom side), 227 nets.

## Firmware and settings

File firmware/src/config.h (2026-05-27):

#define WS2812_DI_PIN GP28

#define ENCODER_A_PINS { GP26 }
#define ENCODER_B_PINS { GP27 }
#define ENCODER_DIRECTION_FLIP

/* Hardware Mapping */
#define RGB_DI_PIN GP0          // The pin connected to your LED 'Data In'
#define RGB_MATRIX_LED_COUNT 98 // Matches your highest index (97) + 1
#define DRIVER_LED_TOTAL RGB_MATRIX_LED_COUNT

/* RGB Matrix Options */
#define RGB_MATRIX_CENTER {112, 32} // The physical center of your board (224/2, 64/2)
#define RGB_MATRIX_KEYPRESSES       // Enables reactive typing effects
#define RGB_MATRIX_FRAMEBUFFER_EFFECTS
#define RGB_MATRIX_KEYRELEASES          // Optional: animations that trigger on key up

/* Power & Performance */
#define RGB_MATRIX_MAXIMUM_BRIGHTNESS 150 // Limits current draw (0-255)
#define RGB_MATRIX_STARTUP_VAL 120        // Default brightness on plug-in
#define RGB_MATRIX_LED_FLUSH_LIMIT 16     // Limits refresh rate to save CPU (16ms = 60fps)

#define ENABLE_RGB_MATRIX_CYCLE_LEFT_RIGHT
#define ENABLE_RGB_MATRIX_CYCLE_UP_DOWN
#define ENABLE_RGB_MATRIX_CYCLE_OUT_IN          // Flows from center to edges
#define ENABLE_RGB_MATRIX_CYCLE_PINWHEEL        // Rotating "fan" of color
#define ENABLE_RGB_MATRIX_CYCLE_SPIRAL          // Spiral pattern from center
#define ENABLE_RGB_MATRIX_DUAL_BEACON           // Two rotating searchlights
#define ENABLE_RGB_MATRIX_RAINBOW_MOVING_CHEVRON
#define ENABLE_RGB_MATRIX_SOLID_REACTIVE_SIMPLE // Light stays on for a moment
#define ENABLE_RGB_MATRIX_SOLID_REACTIVE        // Fades out over time
#define ENABLE_RGB_MATRIX_SPLASH                // Single ripple from keypress
#define ENABLE_RGB_MATRIX_MULTISPLASH           // Allows multiple ripples at once
#define ENABLE_RGB_MATRIX_SOLID_SPLASH          // Solid color ripple
/* Sleep/Suspend Behavior */
#define RGB_DISABLE_WHEN_USB_SUSPENDED true // Turn off lights when PC sleeps
#define RGB_MATRIX_LED_PROCESS_LIMIT 5      // How many LEDs to process per "tick" (performance)

/* Indicator Settings */
#define RGB_MATRIX_TYPING_HEATMAP_DECREASE_DELAY_MS 20 // How fast heatmap fades

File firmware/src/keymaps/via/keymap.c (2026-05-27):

// Copyright 2023 QMK
// SPDX-License-Identifier: GPL-2.0-or-later

#include QMK_KEYBOARD_H

const uint16_t PROGMEM keymaps[][MATRIX_ROWS][MATRIX_COLS] = {
    [0] = LAYOUT(
        KC_ESC, KC_F1, KC_F2, KC_F3, KC_F4, KC_F5, KC_F6, KC_F7, KC_F8, KC_F9, KC_F10, KC_F11, KC_F12, KC_KB_MUTE, KC_KB_VOLUME_DOWN, KC_KB_VOLUME_UP,
        KC_GRV, KC_1, KC_2, KC_3, KC_4, KC_5, KC_6, KC_7, KC_8, KC_9, KC_0, KC_MINS, KC_EQL, KC_BSPC, QK_UNDERGLOW_TOGGLE, RM_VALU,
        KC_TAB, KC_Q, KC_W, KC_E, KC_R, KC_T, KC_Y, KC_U, KC_I, KC_O, KC_P, KC_LBRC, KC_RBRC, KC_BSLS, RM_SPDU, RM_NEXT,
        KC_CAPS, KC_A, KC_S, KC_D, KC_F, KC_G, KC_H, KC_J, KC_K, KC_L, KC_SCLN, KC_QUOT, KC_ENT, RM_VALD, RM_SPDD, RM_PREV,
        KC_LSFT, KC_Z, KC_X, KC_C, KC_V, KC_B, KC_N, KC_M, KC_COMM, KC_DOT, KC_SLSH, KC_RSFT, KC_PGUP, KC_UP, KC_PGDN, KC_NO,
        KC_LCTL, KC_NO, KC_LGUI, KC_LALT, KC_SPC, KC_NO, KC_NO, KC_NO, KC_NO, KC_NO, KC_RALT, KC_RGUI, KC_RCTL, KC_LEFT, KC_DOWN, KC_RIGHT
    )
};

#if defined(ENCODER_MAP_ENABLE)
const uint16_t PROGMEM encoder_map[][NUM_ENCODERS][NUM_DIRECTIONS] = {
    [0] = { ENCODER_CCW_CW(MS_WHLU, MS_WHLD)},
};
#endif

// led_config_t g_led_config = { {
//   // Key Matrix to LED Index
//   { 0, 1, 2, 3, 4, 5, 6, 7, 8, 9,10,11,12,13,14,15 },
//   {33,34,35,36,37,38,39,40,41,42,43,44,45,46,91,16 },
//   {48,49,50,51,52,53,54,55,56,57,58,59,60,61,17,18 },
//   {62,63,64,65,66,67,68,69,70,71,72,73,74,19,20,21 },
//   {75,76,77,78,79,80,81,82,83,84,85,86,22,23,24,28 },
//   {87,88,89,90,92,30,31,32,29,94,95,96,97,25,26,27 },
// }, {
//     // Row 0 (Indices 0-15)
//     {0, 0}, {28, 0}, {40, 0}, {52, 0}, {64, 0}, {76, 0}, {96, 0}, {108, 0}, {120, 0}, {132, 0}, {152, 0}, {164, 0}, {176, 0}, {188, 0}, {208, 0}, {220, 0},
//     // Row 1 (Index 16 is at the end, 33-46, 91)
//     {224, 13}, {212, 26}, {224, 26}, {212, 38}, {224, 38}, {212, 51}, {224, 51}, {212, 64}, {224, 64}, {200, 64}, {188, 64}, {176, 64}, {112, 64}, {100, 64}, {88, 64}, {76, 64},
//     // Row 1 Cont. & Row 2 (Indices 33-61)
//     {0, 13}, {12, 13}, {24, 13}, {36, 13}, {48, 13}, {60, 13}, {72, 13}, {84, 13}, {96, 13}, {108, 13}, {120, 13}, {132, 13}, {144, 13}, {164, 13}, {188, 26}, {6, 26},
//     {22, 26}, {34, 26}, {46, 26}, {58, 26}, {70, 26}, {82, 26}, {94, 26}, {106, 26}, {118, 26}, {130, 26}, {142, 26}, {154, 26}, {168, 26}, {0, 64}, // 91 (UG?)
//     // Row 3 (Indices 62-74 + Numpad/Nav 19-21)
//     {8, 38}, {26, 38}, {38, 38}, {50, 38}, {62, 38}, {74, 38}, {86, 38}, {98, 38}, {110, 38}, {122, 38}, {134, 38}, {146, 38}, {168, 38}, {188, 38}, {200, 38}, {212, 38},
//     // Row 4 (Indices 75-86 + Numpad/Nav 22-24, 28)
//     {11, 51}, {32, 51}, {44, 51}, {56, 51}, {68, 51}, {80, 51}, {92, 51}, {104, 51}, {116, 51}, {128, 51}, {140, 51}, {165, 51}, {188, 51}, {200, 51}, {212, 51}, {224, 51},
//     // Row 5 (Indices 87-90, 92, 30-32, 29, 94-97 + 25-27)
//     {0, 64}, {12, 64}, {24, 64}, {36, 64}, {80, 64}, {120, 64}, {135, 64}, {148, 64}, {168, 64}, {188, 64}, {200, 64}, {212, 64}, {224, 64}, {200, 64}, {212, 64}, {224, 64}}, {
// }, {
//   // LED Index to Flag
//       1, 1, 1, 1, 1, 1, 1, 1, 1, 1, 1, 1, 1, 1, 1, 1,
//       1, 1, 1, 1, 1, 1, 1, 1, 1, 1, 1, 1, 1, 1, 1, 1,
//       1, 1, 1, 1, 1, 1, 1, 1, 1, 1, 1, 1, 1, 1, 1, 1,
//       1, 1, 1, 1, 1, 1, 1, 1, 1, 1, 1, 1, 1, 1, 1, 1,
//       1, 1, 1, 1, 1, 1, 1, 1, 1, 1, 1, 1, 1, 1, 1, 1,
//       1, 1, 1, 1, 1, 1, 1, 1, 1, 1, 1, 1, 1, 1, 1, 1 
// } };

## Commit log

2026-03-06 Update BOM
2026-03-06 Added gerbers
    [bom.csv, designators.csv, positions.csv]
2026-03-07 Ready for submission
    [bom.csv]
2026-03-17 Updated PCB slightly
    [pcb.kicad_pcb]
